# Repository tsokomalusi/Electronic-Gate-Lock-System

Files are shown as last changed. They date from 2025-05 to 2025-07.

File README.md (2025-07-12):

# Electronic-Gate-Lock-System

## Schematic capture
egls_schematic

## 4-Layer PCB Layout
egls_4layer_pcb

## 3D Model
egls_3D

## Block Diagram
egls_block_diagram

## Fabricated PCB


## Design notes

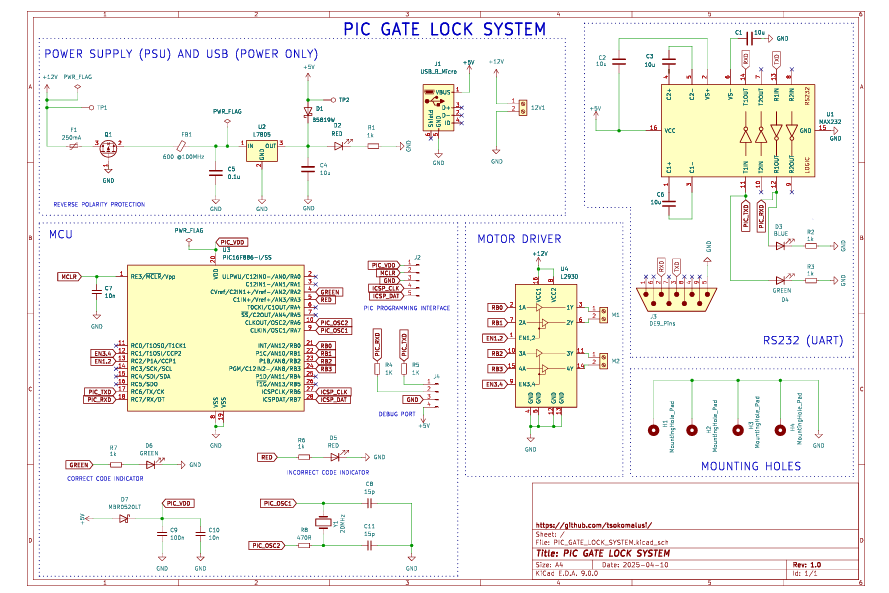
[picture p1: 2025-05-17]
Images/egls_schematic.png

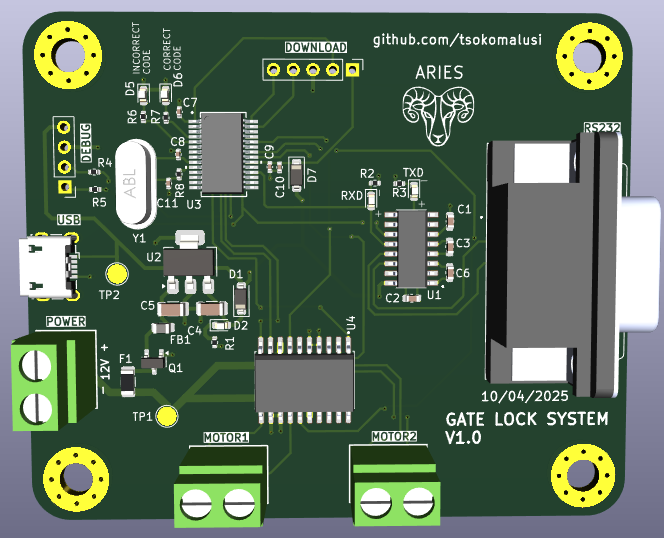
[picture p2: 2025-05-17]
Images/egls_3D.png

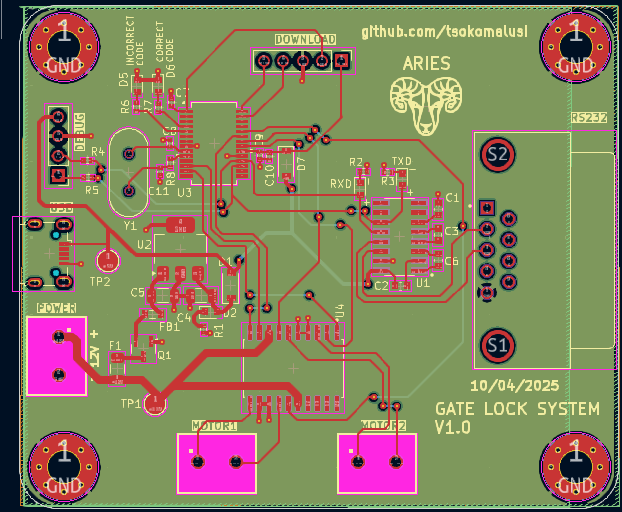
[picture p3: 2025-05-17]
Images/egls_4layer_pcb.png

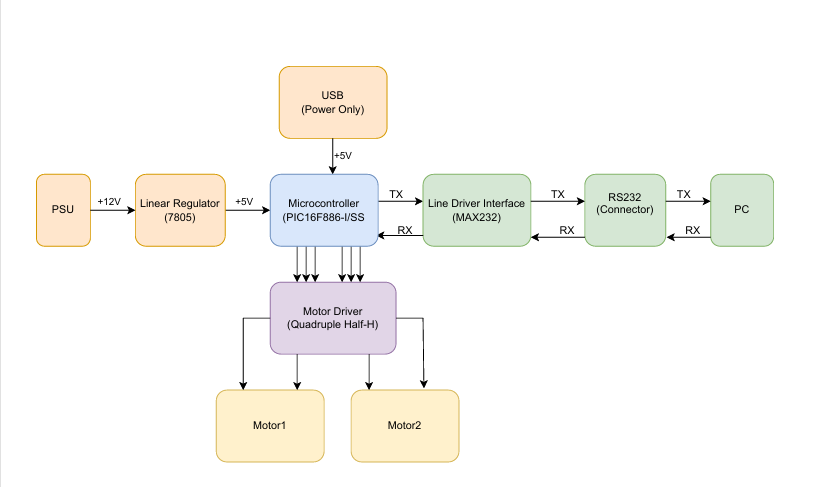
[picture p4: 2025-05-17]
Images/egls_block_diagram.png

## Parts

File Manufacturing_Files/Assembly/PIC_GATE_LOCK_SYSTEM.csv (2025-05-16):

Reference | Qty | Value | DNP | Exclude from BOM | Exclude from Board | Footprint | Datasheet
12V1,M1,M2 | 3 | Screw_Terminal_01x02 |  |  |  | Connector_TE-Connectivity:691137710002 | ~
C1,C2,C3,C6 | 4 | 10u |  |  |  | Capacitor_SMD:C_0603_1608Metric | ~
C4 | 1 | 10u |  |  |  | Capacitor_SMD:C_1206_3216Metric | ~
C5 | 1 | 0.1u |  |  |  | Capacitor_SMD:C_1206_3216Metric | ~
C7,C10 | 2 | 10n |  |  |  | Capacitor_SMD:C_0402_1005Metric | ~
C8,C11 | 2 | 15p |  |  |  | Capacitor_SMD:C_0402_1005Metric | ~
C9 | 1 | 100n |  |  |  | Capacitor_SMD:C_0402_1005Metric | ~
D1 | 1 | B5819W |  |  |  | Diode_SMD:D_SOD-123 | ~
D2,D5 | 2 | RED |  |  |  | LED_SMD:LED_0603_1608Metric | ~
D3 | 1 | BLUE |  |  |  | LED_SMD:LED_0603_1608Metric | ~
D4,D6 | 2 | GREEN |  |  |  | LED_SMD:LED_0603_1608Metric | ~
D7 | 1 | MBR0520LT |  |  |  | Diode_SMD:D_SOD-123 | http://www.onsemi.com/pub_link/Collateral/MBR0520LT1-D.PDF
F1 | 1 | 250mA |  |  |  | Fuse:Fuse_1206_3216Metric | ~
FB1 | 1 | 600 @100MHz |  |  |  | Inductor_SMD:L_0805_2012Metric | ~
H1,H2,H3,H4 | 4 | MountingHole_Pad |  | Excluded from BOM |  | MountingHole:MountingHole_4.3mm_M4_Pad_Via | ~
J1 | 1 | USB_B_Micro |  |  |  | Connector_USB:USB_Micro-B_Wuerth_629105150521 | ~
J2 | 1 | Conn_01x05_Pin |  |  |  | Connector_PinHeader_2.54mm:PinHeader_1x05_P2.54mm_Vertical | ~
J3 | 1 | DE9_Pins |  |  |  | Connector_Dsub:A-DF_09_A_KG-T4S | ~
J4 | 1 | Conn_01x04_Pin |  |  |  | Connector_PinHeader_2.54mm:PinHeader_1x04_P2.54mm_Vertical | ~
Q1 | 1 | AO3401A |  |  |  | Package_TO_SOT_SMD:SOT-23 | http://www.aosmd.com/pdfs/datasheet/AO3401A.pdf
R1,R2,R3,R6,R7 | 5 | 1k |  |  |  | Resistor_SMD:R_0402_1005Metric | ~
R4,R5 | 2 | 1K |  |  |  | Resistor_SMD:R_0402_1005Metric | ~
R8 | 1 | 470R |  |  |  | Resistor_SMD:R_0402_1005Metric | ~
TP1,TP2 | 2 | TestPoint |  |  |  | TestPoint:TestPoint_Pad_D2.5mm | ~
U1 | 1 | MAX232 |  |  |  | Package_SO:SOIC127P600X175-16N | http://www.ti.com/lit/ds/symlink/max232.pdf
U2 | 1 | L7805 |  |  |  | Package_TO_SOT_SMD:SOT-223 | http://www.st.com/content/ccc/resource/technical/document/datasheet/41/4f/b3/b0/12/d4/47/88/CD00000444.pdf/files/CD00000444.pdf/jcr:content/translations/en.CD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
U3 | 1 | PIC16F886-I/SS |  |  |  | Package_SO:SSOP28_MC_MCH | http://ww1.microchip.com/downloads/en/DeviceDoc/41291D.pdf
U4 | 1 | L293D |  |  |  | Package_SO:SOIC127P1032X265-20N | http://www.ti.com/lit/ds/symlink/l293.pdf
Y1 | 1 | 20MHz |  |  |  | Connector_Dsub:XTAL_HC49P488W46L1150T500H350 | ~

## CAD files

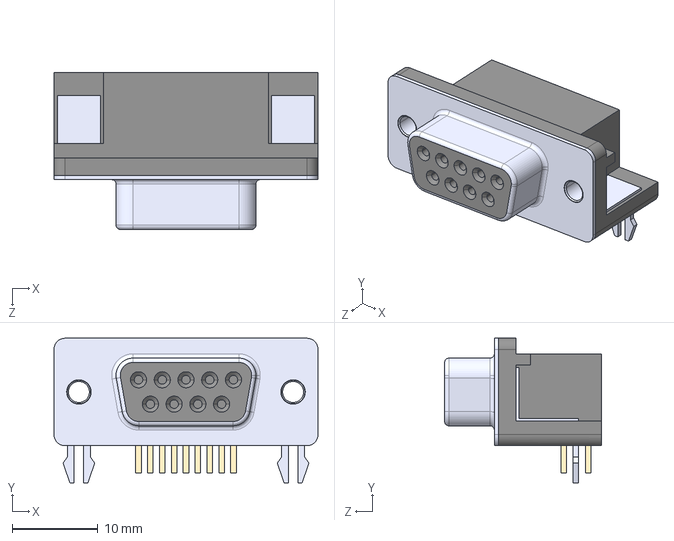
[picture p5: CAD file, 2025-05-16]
Step_Files/A-DF_09_A_KG-T4S.step
30.8 x 16.9 x 18.3 mm

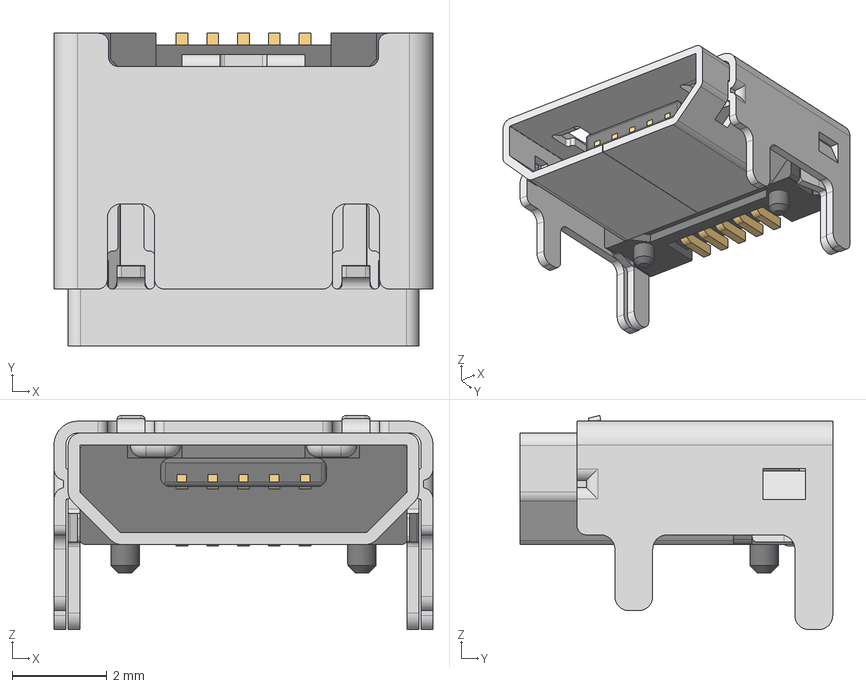
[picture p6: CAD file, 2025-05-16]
Step_Files/Download_STP_629105150521_rev1.stp
8.00 x 6.60 x 4.52 mm
629105150521_Housing
629105150521_Pin1 x 4
629105150521_Pin2
629105150521_Shielding2
629105150521_Shielding

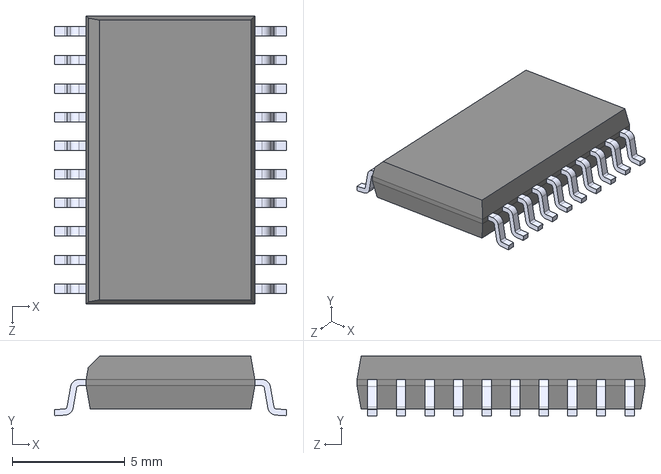
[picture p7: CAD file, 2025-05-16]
Step_Files/L293DD.step
10.3 x 2.65 x 12.8 mm

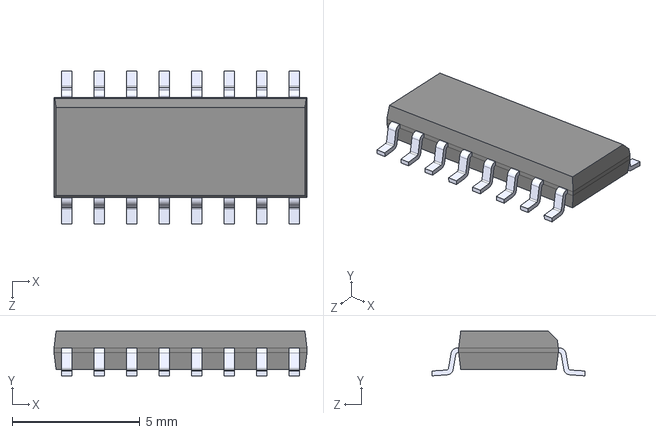
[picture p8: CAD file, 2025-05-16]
Step_Files/MAX232DR.step
9.90 x 1.75 x 6.00 mm

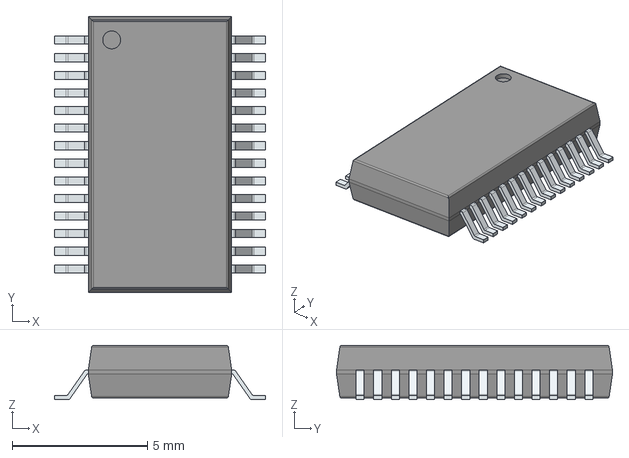
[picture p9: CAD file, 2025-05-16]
Step_Files/PIC16F886-I_SS.stp
7.80 x 10.2 x 2.00 mm
PinsArrayLR

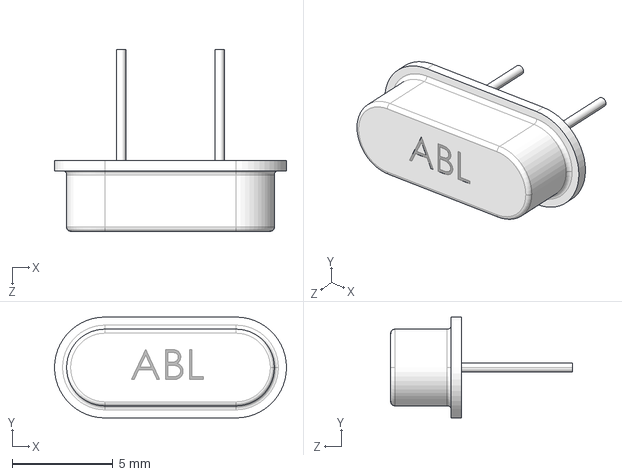
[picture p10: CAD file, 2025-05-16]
Step_Files/ABL-20.000MHZ-B2.step
11.5 x 5.00 x 9.00 mm

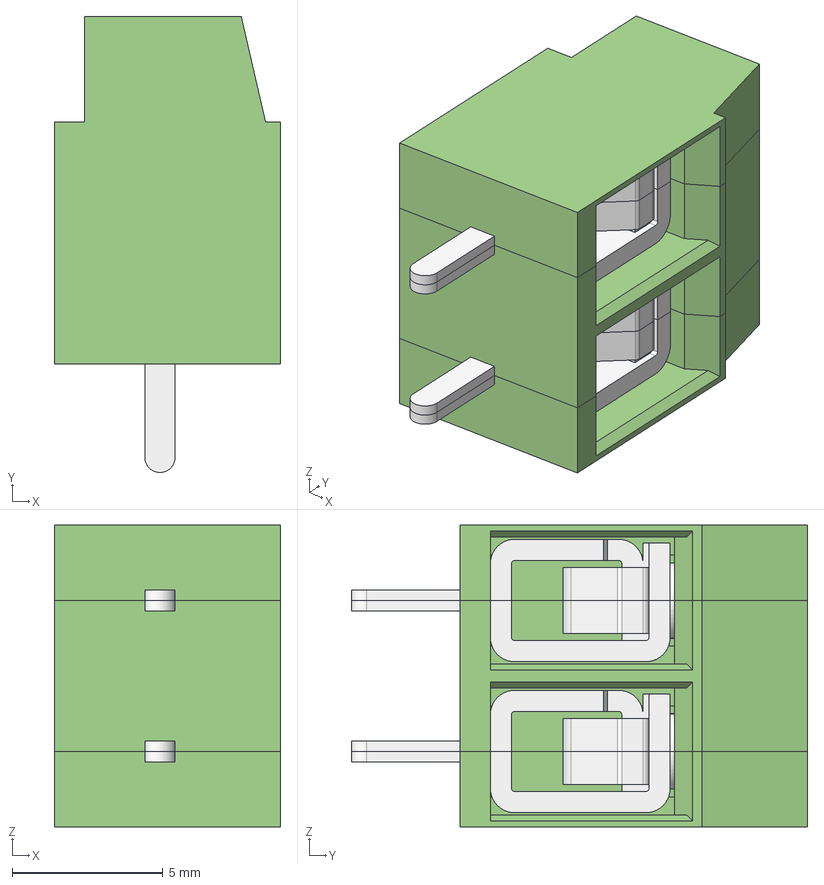
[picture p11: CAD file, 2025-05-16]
Step_Files/691137710002.step
7.50 x 15.1 x 10.0 mm
MRT12P5_SX
MRT12P5_CNT
MRT12P5_DX

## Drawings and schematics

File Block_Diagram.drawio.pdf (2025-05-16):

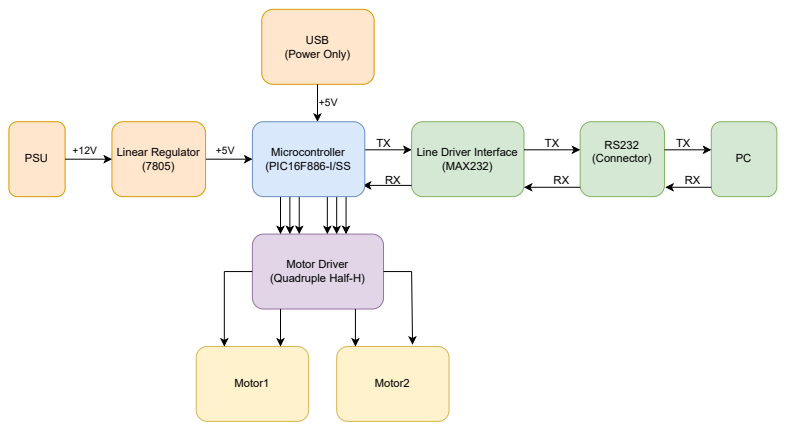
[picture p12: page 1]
Motor Driver (Quadruple Half-H); PSU; Linear Regulator; USB (Power Only); (Connector); Motor1; Motor2; Microcontroller (PIC16F886-I/SS

Line Driver Interface
(MAX232)

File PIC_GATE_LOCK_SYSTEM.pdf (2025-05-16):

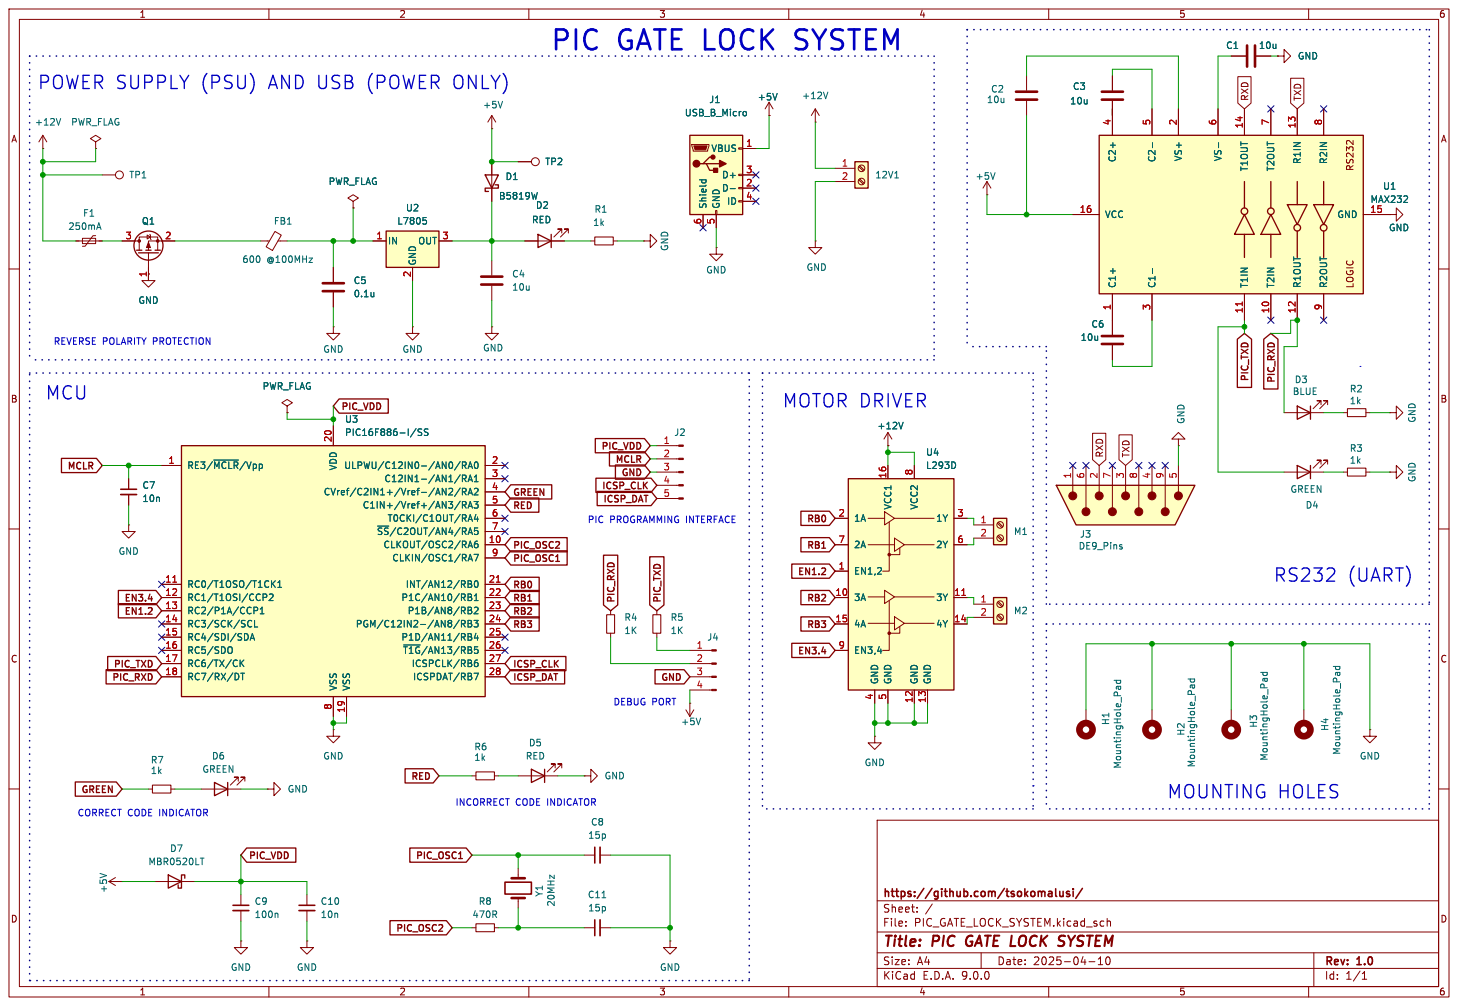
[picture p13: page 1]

8 VSS 19 ULPWU/C12IN0-/AN0/RA0 2 C12IN1-/AN1/RA1 3 CVref/C2IN1+/Vref-/AN2/RA2 4 C1IN+/Vref+/AN3/RA3 5 T0CKI/C1OUT/RA4 6 ~{SS}/C2OUT/AN4/RA5 7 CLKOUT/OSC2/RA6 10 CLKIN/OSC1/RA7 9

File: PIC_GATE_LOCK_SYSTEM.kicad_sch Sheet: / https://github.com/tsokomalusi/

Id: 1/1 Title: PIC GATE LOCK SYSTEM

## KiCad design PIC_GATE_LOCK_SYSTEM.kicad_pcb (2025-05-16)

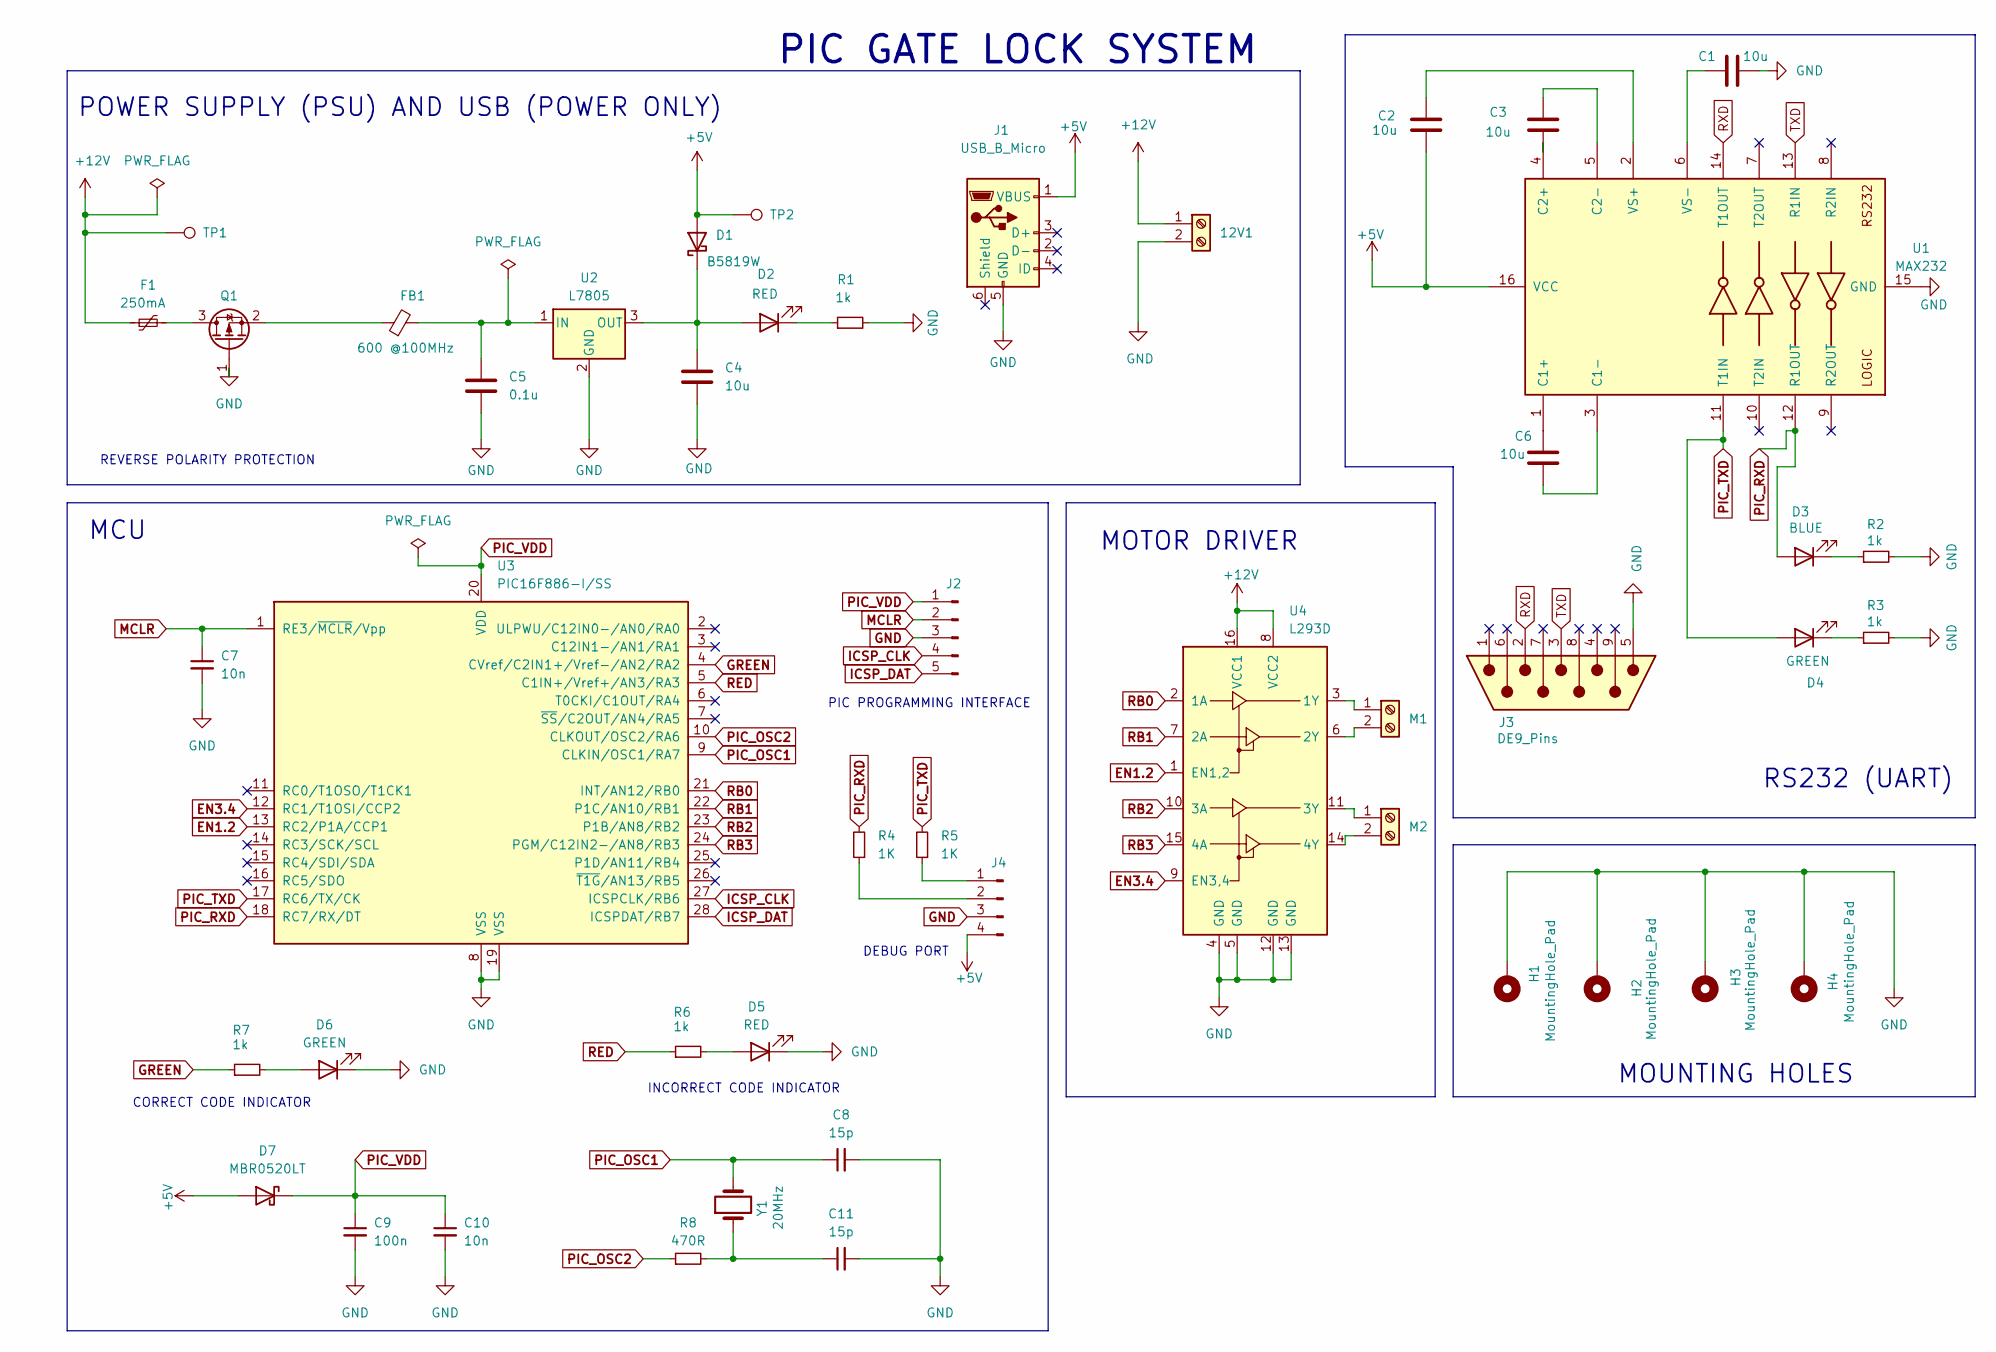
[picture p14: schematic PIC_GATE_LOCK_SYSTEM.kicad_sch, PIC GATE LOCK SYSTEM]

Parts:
12V1: Screw_Terminal_01x02; 691137710002
C1, C2, C3, C6: 10u; C_0603_1608Metric
C4: 10u; C_1206_3216Metric
C5: 0.1u; C_1206_3216Metric
C7, C10: 10n; C_0402_1005Metric
C8, C11: 15p; C_0402_1005Metric
C9: 100n; C_0402_1005Metric
D1: B5819W; D_SOD-123
D2, D5: RED; LED_0603_1608Metric
D3: BLUE; LED_0603_1608Metric
D4, D6: GREEN; LED_0603_1608Metric
D7: MBR0520LT; D_SOD-123
F1: 250mA; Fuse_1206_3216Metric
FB1: 600 @100MHz; L_0805_2012Metric
H1, H2, H3, H4: MountingHole_Pad; MountingHole_4.3mm_M4_Pad_Via
J1: USB_B_Micro; USB_Micro-B_Wuerth_629105150521
J2: Conn_01x05_Pin; PinHeader_1x05_P2.54mm_Vertical
J3: DE9_Pins; A-DF_09_A_KG-T4S
J4: Conn_01x04_Pin; PinHeader_1x04_P2.54mm_Vertical
M1, M2: Screw_Terminal_01x02; 691137710002
Q1: AO3401A; SOT-23
R1, R2, R3, R6, R7: 1k; R_0402_1005Metric
R4, R5: 1K; R_0402_1005Metric
R8: 470R; R_0402_1005Metric
TP1, TP2: TestPoint; TestPoint_Pad_D2.5mm
U1: MAX232; SOIC127P600X175-16N
U2: L7805; SOT-223
U3: PIC16F886-I/SS; SSOP28_MC_MCH
U4: L293D; SOIC127P1032X265-20N
Y1: 20MHz; XTAL_HC49P488W46L1150T500H350

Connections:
+5V: C2.1, D1.2 (A), D7.2 (A), J1.1 (VBUS), J4.4, TP2.1, U1.16 (VCC)
+12V: 12V1.1, F1.1, TP1.1, U4.8 (VCC2), U4.16 (VCC1)
EN1.2: U3.13 (RC2/P1A/CCP1), U4.1 (EN1,2)
EN3.4: U3.12 (RC1/T1OSI/CCP2), U4.9 (EN3,4)
GND: 12V1.2, C1.2, C4.2, C5.2, C7.2, C8.2, C9.2, C10.2, C11.2, D5.1 (K), D6.1 (K), H1.1, H2.1, H3.1, H4.1, J1.5 (GND), J2.3, J3.5, J4.3, Q1.1 (G), R1.2, R2.2, R3.2, U1.15 (GND), U2.2 (GND), U2.4, U3.8 (VSS), U3.19 (VSS), U4.4 (GND), U4.5 (GND), U4.12 (GND), U4.13 (GND)
GREEN: R7.1, U3.4 (CVref/C2IN1+/Vref-/AN2/RA2)
ICSP_CLK: J2.4, U3.27 (ICSPCLK/RB6)
ICSP_DAT: J2.5, U3.28 (ICSPDAT/RB7)
MCLR: C7.1, J2.2, U3.1 (RE3/~MCLR/Vpp)
unnamed: C11.1, R8.2, Y1.1
unnamed: C4.1, D1.1 (K), D2.2 (A), U2.3 (OUT)
unnamed: D2.1 (K), R1.1
unnamed 12: D3.1 (K), R2.1; also elsewhere on the board
unnamed 13: D4.1 (K), R3.1; also elsewhere on the board
unnamed: D5.2 (A), R6.2
unnamed: D6.2 (A), R7.2
unnamed: J4.1, R5.1
unnamed: J4.2, R4.1
unnamed: M1.1, U4.3 (1Y)
unnamed: M1.2, U4.6 (2Y)
unnamed: M2.1, U4.11 (3Y)
unnamed: M2.2, U4.14 (4Y)
unnamed: F1.2, Q1.3 (D)
unnamed: FB1.1, Q1.2 (S)
unnamed: C6.1, U1.1 (C1+)
unnamed: C6.2, U1.3 (C1-)
unnamed: C3.1, U1.4 (C2+)
unnamed: C3.2, U1.5 (C2-)
unnamed: C2.2, U1.2 (VS+)
unnamed: C1.1, U1.6 (VS-)
unnamed: C5.1, FB1.2, U2.1 (IN)
PIC_OSC1: C8.1, U3.9 (CLKIN/OSC1/RA7), Y1.2
PIC_OSC2: R8.1, U3.10 (CLKOUT/OSC2/RA6)
PIC_RXD: D3.2 (A), R4.2, U1.12 (R1OUT), U3.18 (RC7/RX/DT); also elsewhere on the board
PIC_TXD: D4.2 (A), R5.2, U1.11 (T1IN), U3.17 (RC6/TX/CK); also elsewhere on the board
PIC_VDD: C9.1, C10.1, D7.1 (K), J2.1, U3.20 (VDD)
RB0: U3.21 (INT/AN12/RB0), U4.2 (1A)
RB1: U3.22 (P1C/AN10/RB1), U4.7 (2A)
RB2: U3.23 (P1B/AN8/RB2), U4.10 (3A)
RB3: U3.24 (PGM/C12IN2-/AN8/RB3), U4.15 (4A)
RED: R6.1, U3.5 (C1IN+/Vref+/AN3/RA3)
RXD: J3.2, U1.14 (T1OUT)
TXD: J3.3, U1.13 (R1IN)

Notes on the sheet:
REVERSE POLARITY PROTECTION
PIC PROGRAMMING INTERFACE
MCU
DEBUG PORT
RS232 (UART)
PIC GATE LOCK SYSTEM
MOTOR DRIVER
POWER SUPPLY (PSU) AND USB (POWER ONLY)
INCORRECT CODE INDICATOR
MOUNTING HOLES
CORRECT CODE INDICATOR

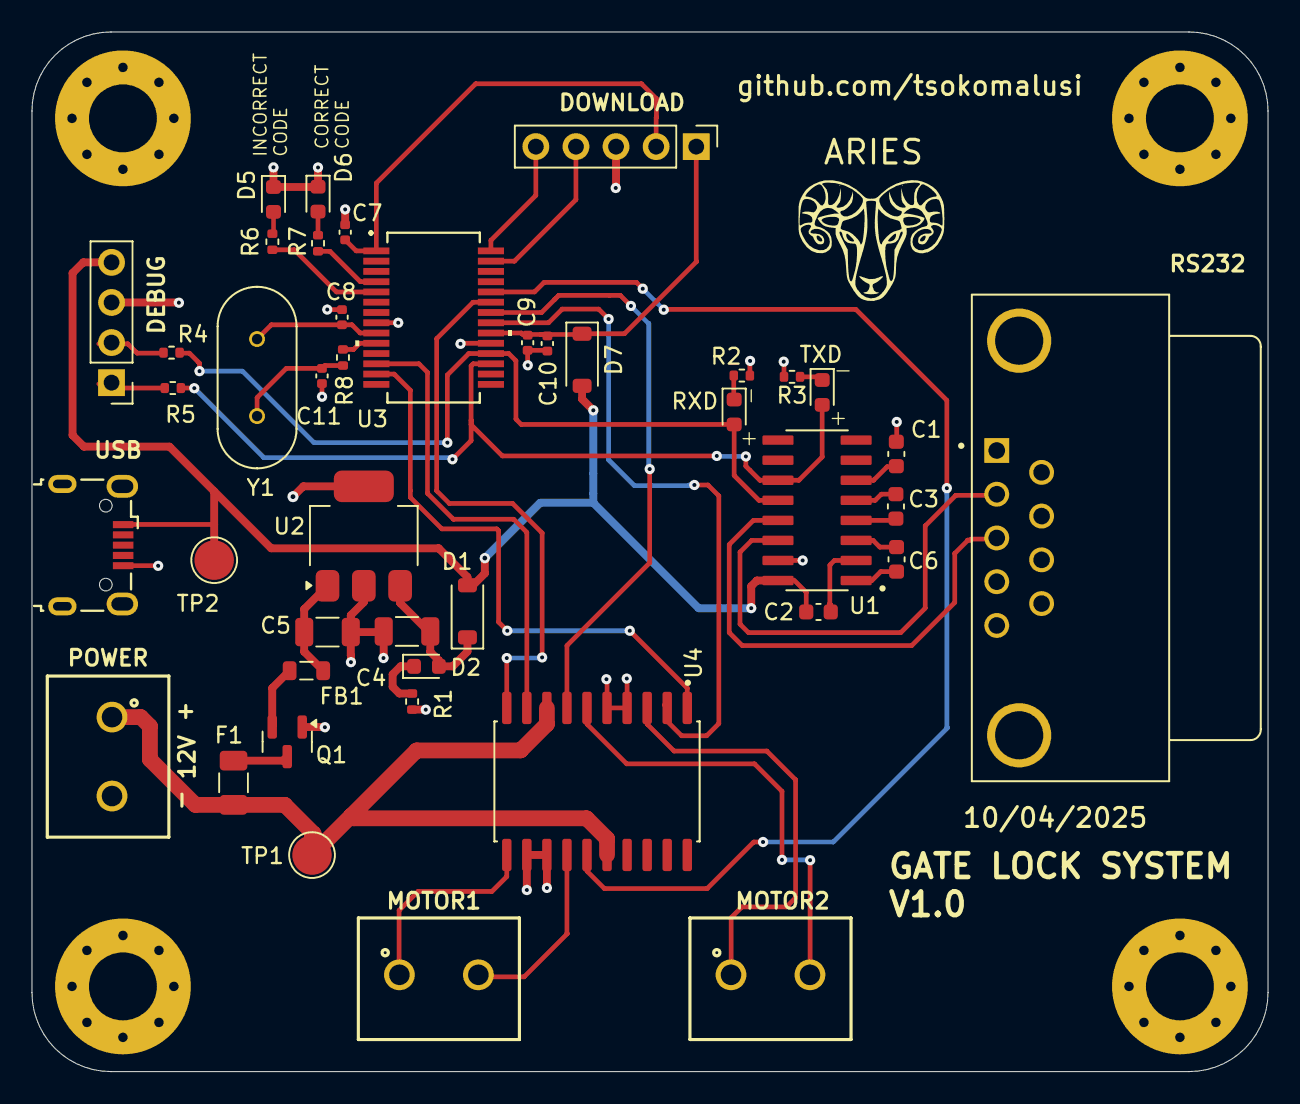
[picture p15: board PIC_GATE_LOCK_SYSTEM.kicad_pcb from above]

Board: 4 copper layers, 78.3 x 65.8 mm, 47 parts (0 on the bottom side), 43 nets.

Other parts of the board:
RXD: BLUE; LED_0603_1608Metric
TXD: GREEN; LED_0603_1608Metric

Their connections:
unnamed 12: RXD.1 (K); also elsewhere on the board
unnamed 13: TXD.1 (K); also elsewhere on the board
PIC_RXD: RXD.2 (A); also elsewhere on the board
PIC_TXD: TXD.2 (A); also elsewhere on the board
